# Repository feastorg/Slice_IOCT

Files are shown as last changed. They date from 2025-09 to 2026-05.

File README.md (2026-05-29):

# Slice Template

Rugged digital I/O controller slice with isolated inputs and protected outputs for industrial sensors and actuators.

Template for creating BREAD slices. Features Arduino Nano, small dimensions (70x100mm), 2 layers, and this is the second revision (TEMP_NANO_S2L-r2).

## Introduction

This Slice is designed to be a rugged digital input and output slice that can interface directly with 24V industrial sensors and actuators. It mimics a PLC-style IO module for the BREADS system. It prioritizes input protection, reliable switching, and compatibility with common field devices.

## Usage

[Explain how to use the project. Include examples and screenshots if applicable.]

## Documentation

Please refer to the [docs](/docs) for more info.

---

<div align="center">
  <p>
    
    
  </p>
</div>

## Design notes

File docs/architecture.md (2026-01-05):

---
title: "Architecture Overview"
description: "High-level architecture: electrical, firmware, and mechanical design notes."
---

Overview of the electrical, firmware, and mechanical design of this Slice.

## Rough Plan for SLC_IOCT

TODO: remove this and disperse relevant info into appropriate sections below as they are fleshed out.

**Goal / Description:**

- Create a slice for rugged **digital I/O** control in industrial or field settings.
- Interface directly with **24 V sensors and actuators**.
- Mimics a simple **PLC-style I/O module** for the BREADS system.
- Prioritize **input protection**, reliable switching, and compatibility with common field devices.

**Design Plan:**

- 4–8 opto-isolated digital inputs (24 V-compatible)
- 4–8 protected digital outputs using onboard SSR relays
- TVS protection, flyback diodes for inductive loads

**Applications:**

- Switches, proximity sensors, and relays in automation systems
- Basic on/off control of 24 V field devices
- Rugged I/O for robotics, process control, or lab automation

## 🧠 Purpose

<!-- Briefly describe the function of the Slice -->

This Slice is designed to be a rugged digital input and output slice that can interface directly with 24V industrial sensors and actuators. It mimics a PLC-style IO module for the BREADS system. It prioritizes input protection, reliable switching, and compatibility with common field devices.

## 🔌 Interfaces

| Signal | Connector  | Direction | Voltage | Notes |
| --- | --- | --- | --- | --- |
| IN1 | Screw down | Input | 24V | High voltage input  |
| IN2 | Screw down | Input | 24V | High voltage input  |
| IN3 | Screw down | Input | 24V | High voltage input  |
| IN4 | Screw down | Input | 24V | High voltage input  |
| IN5 | Screw down | Input | 24V | High voltage input  |
| IN6 | Screw down | Input | 24V | High voltage input  |
| OUT1 | Screw down | Output | 12V/24V | High voltage output |
| OUT2 | Screw down | Output | 12V/24V | High voltage output |
| OUT3 | Screw down | Output | 12V/24V | High voltage output |
| OUT4 | Screw down | Output | 12V/24V | High voltage output |

## 🪛 MCU Pin Mapping

| MCU Pin | Function | Net  | Notes |
| --- | --- | ---- | ----- |
| D6 | IN1 | IN1  | |
| D7 | IN3 | IN3  | |
| D8 | IN5 | IN5  | |
| D9 | IN6 | IN6  | |
| D10 | IN4 | IN4  | |
| D11 | IN2 | IN2  | |
| A0 | OUT1 | OUT1 | |
| A1 | OUT2 | OUT2 | |
| A2 | OUT3 | OUT3 | |
| A3 | OUT4 | OUT4 | |

### DUMP

- Supported MCU Dev Boards:
  - Arduino Nano Original (ATMega328P)
  - Arduino Nano Every (ATMega4809)
  - STM32 Nucleo-32 series (e.g. L432KC, F303K8)
  - Other Nano-format boards also supported:
    - Any MCU board using the standard Arduino Nano pinout and 0.1" dual-row 15x2 header format
    - Nano ESP32 and ESP32-S2 variants with Nano footprint (e.g. Nano ESP32 by Arduino, or 3rd party clones)
    - RP2040 Nano-form boards (e.g. Nano RP2040 Connect, Seeed Studio RP2040 Nano)
    - CH32V203 or CH32V003 Nano-format RISC-V dev boards

## 🔋 Power Domains

- Logic power: 5V
- High-current domain: 12V/24V

## 🧩 Mechanical

- Mounting pattern: ...
- Dimensions: ...
- Notes: ...

---

<!-- Optional: Add block diagrams or images under docs/assets/ -->

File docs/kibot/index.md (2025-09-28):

---
title: "KiBot Outputs"
description: "Index for KiBot-generated PCB artifacts."
layout: "page"
---

These are the docs & KiBot Outputs for Slice TEMP NANO S2L r2

The following files were generated from the latest PCB build:

- [Schematic.pdf](./Schematic.pdf)
- [PCB.pdf](./PCB.pdf)
- [kibot.log](./kibot.log)
- [BREAD_Slice-bom.html](./BREAD_Slice-bom.html)
- [BREAD_Slice-ibom.html](./BREAD_Slice-ibom.html)

_Last updated automatically on 2025-09-28 at 17:45:11 UTC by KiBot via GitHub Actions._

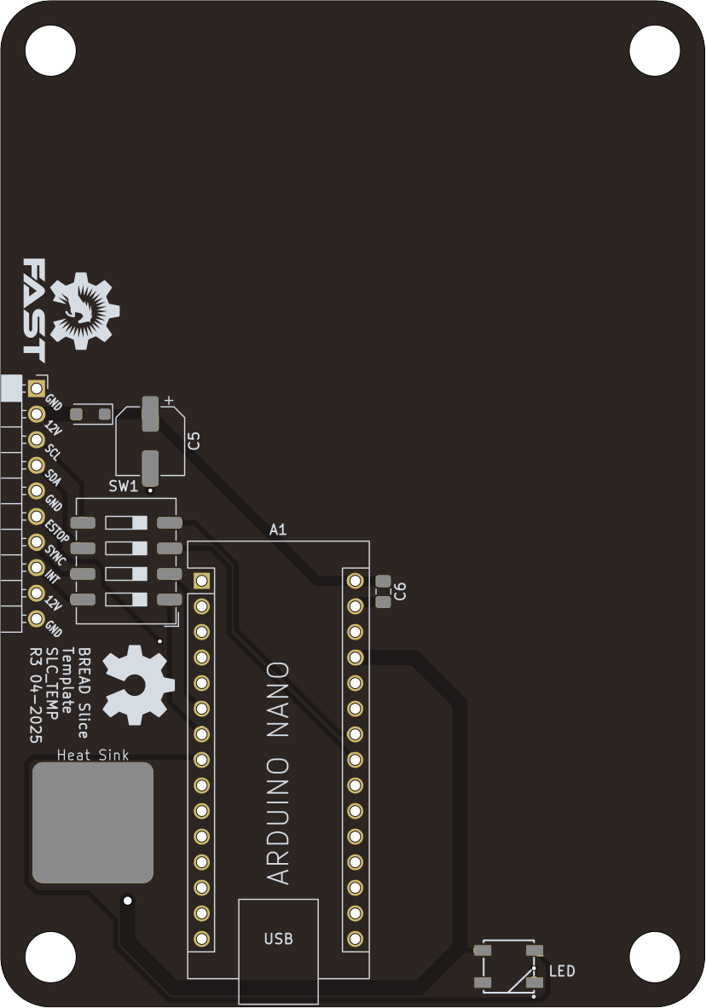
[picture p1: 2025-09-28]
docs/assets/boards/board_top.png

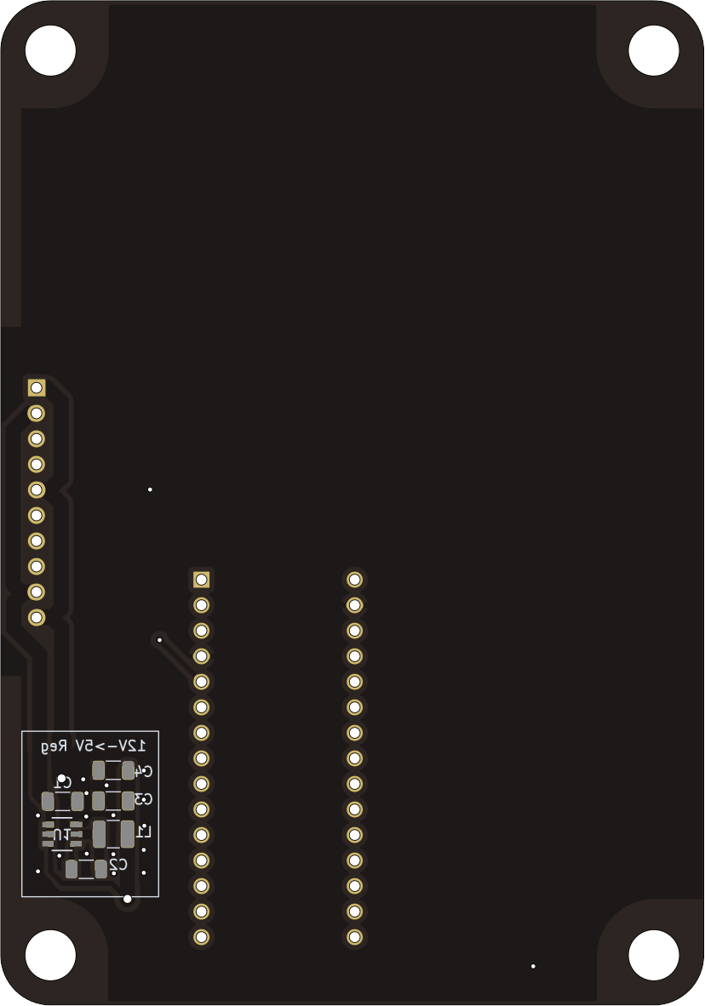
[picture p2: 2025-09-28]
docs/assets/boards/board_bottom.png

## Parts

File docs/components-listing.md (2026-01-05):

# Componments Listing

24v input protection electrolytic cap: https://www.digikey.ca/en/products/detail/panasonic-electronic-components/EEE-FK1V100UR/766003

To use:

- [12 POS - Fixed Terminal Blocks PTSA 0.5/12-2.5-Z 12P 2.5MM 45DEG - Mouser Canada](https://mou.sr/3Xod5Gt)
- [2 POS - Fixed Terminal Blocks PTSA 1.5/2-3.5-Z 2P 3.5MM 45DEG - Mouser Canada](https://mou.sr/3LWcRnp)

Diff number of positions of same line:

- [Fixed Terminal Blocks PTSA 0.5/ 4-2.5-F](https://mou.sr/4qVzBUy)
- [Fixed Terminal Blocks PTSA 0.5/16-2.5-Z](https://mou.sr/3JO0I3o)
- [Fixed Terminal Blocks PTSA 1.5/16-3.5-Z](https://mou.sr/4qV1MDa)

Other options that cam should move somewhere as he gets his shit together deciding a connector series to main (we should have main PTSA since it offers 2.5 and 3.5mm and then maybe LPT for higher power use):

- [LPT(A) 2.5 Lever Push-In Terminal Blocks - Mouser Search](https://www.mouser.ca/c/connectors/terminal-blocks/fixed-terminal-blocks/?marcom=196874227&instock=y)
- [TDPT 2,5/ 2-SP-5,08 - PCB terminal block - Phoenix Contact Site](https://www.phoenixcontact.com/en-ca/products/printed-circuit-board-terminal-tdpt-25-2-sp-508-1017503)
- [LPT 2,5/ 4-5,0 - PCB terminal block - Phoenix Contact Site](https://www.phoenixcontact.com/en-ca/products/printed-circuit-board-terminal-lpt-25-4-50-1190299)
- [SPTA 1/ 2-3,5 - PCB terminal block - Phoenix Contact Site](https://www.phoenixcontact.com/en-ca/products/printed-circuit-board-terminal-spta-1-2-35-1752104)

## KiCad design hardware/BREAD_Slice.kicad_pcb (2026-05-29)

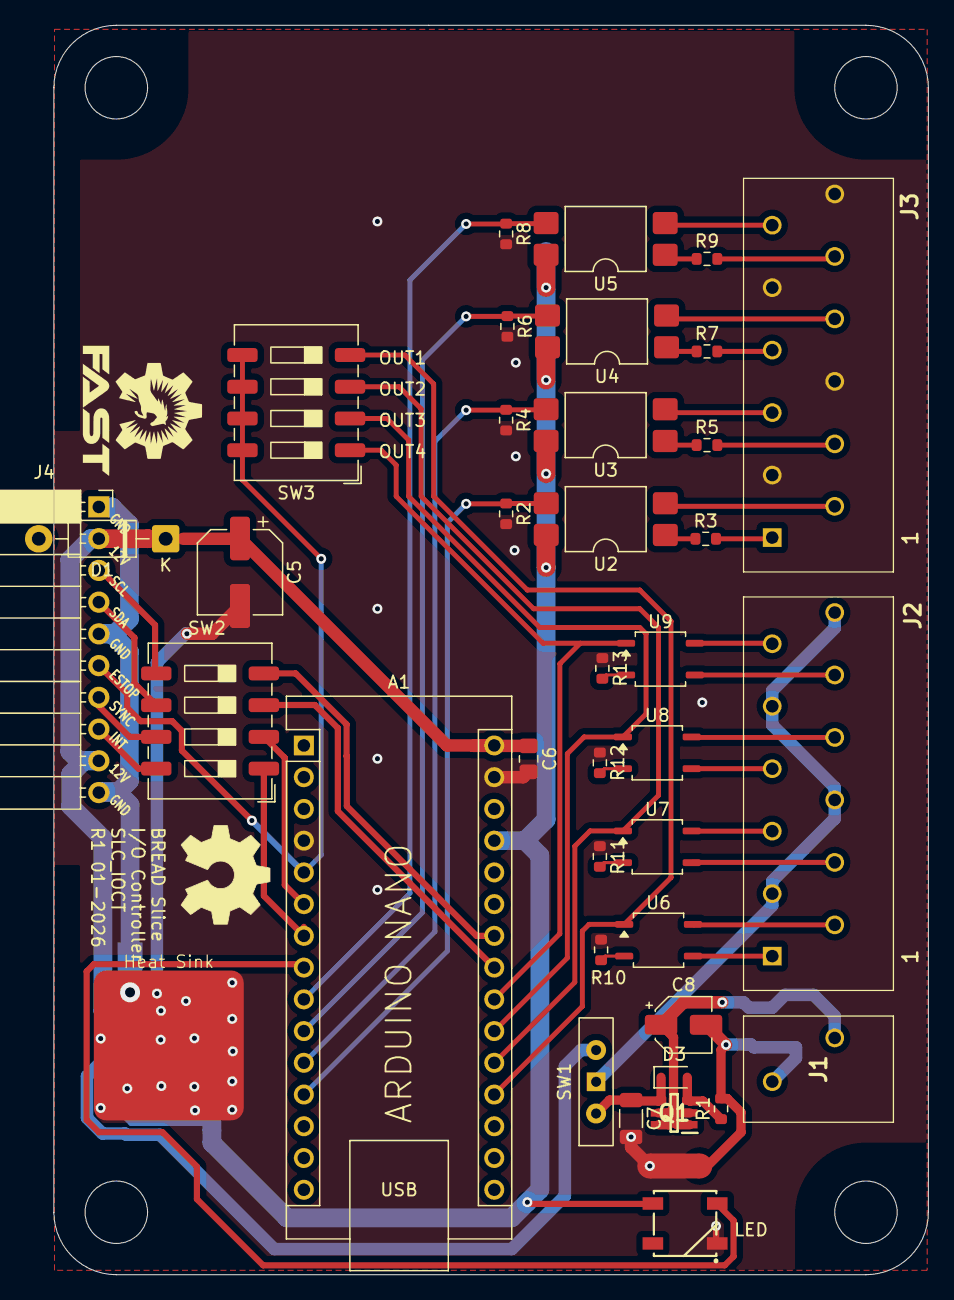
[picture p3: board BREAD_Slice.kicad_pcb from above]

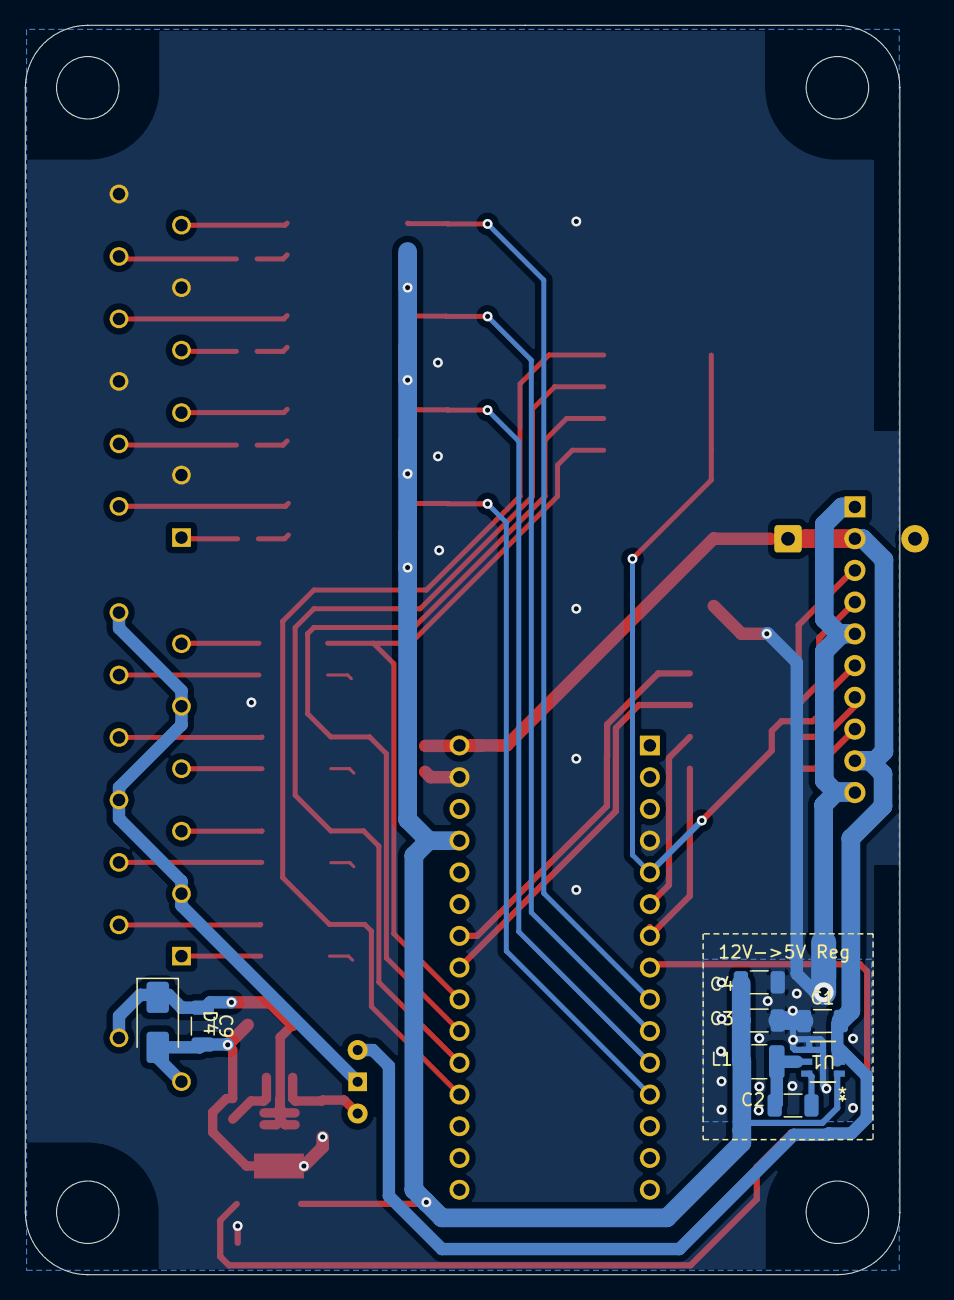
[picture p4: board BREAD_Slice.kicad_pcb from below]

Board: 2 copper layers, 70.0 x 100.0 mm, 53 parts (9 on the bottom side), 54 nets.

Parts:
A1: Arduino_Nano_v3.x; Arduino_Nano
C1: 10u; C_1206_3216Metric
C2: 100nF; C_1206_3216Metric
C3, C4: 22uF; C_1206_3216Metric
C5: 47u 25V; CP_Elec_6.3x7.7
C6: 0.1u; C_0805_2012Metric_Pad1.18x1.45mm_HandSolder
C7, C9: 100n; C_1206_3216Metric
C8: 10u; CP_Elec_4x5.8
D1: 1N4007; D_DO-41_SOD81_P10.16mm_Horizontal
D2: WS2812B_5050; WS2812-5050-4PIN
D3: MM3Z18VT1G; D_SOD-323
D4: SMAJ24CA; D_SMA
H1, H2, H3, H4: MountingHole; MountingHole_5mm
HS1: Heatsink_Pad; Thermal Pad
J1: 1985195
J2, J3: 1990106
J4: Conn_01x10_Socket; PinSocket_1x10_P2.54mm_Horizontal
L1: 4.7uH; L_1210_3225Metric
NT1, NT2: NetTie_2; NetTie-2_SMD_Pad2.0mm
Q1: NTGS4111PT1G; SOT95P275X110-6N
R1: 100k; R_0603_1608Metric
R2, R3, R4, R5, R6, R7, R8, R9: 1k; R_0603_1608Metric
R10, R11, R12, R13: 1.3k; R_0603_1608Metric
Ref**: Val**; OSHW_Logo_8mm
SW1: SW_SPDT; SW_Slide-03_Wuerth-WS-SLTV_10x2.5x6.4_P2.54mm
SW2, SW3: SW_DIP_x04; SW_DIP_SPSTx04_Slide_9.78x12.34mm_W8.61mm_P2.54mm
U1: AP63205; SOIC_05WU-7_DIO
U2, U3, U4, U5: LTV-817S; SMDIP-4_W9.53mm
U6, U7, U8, U9: CPC1002N; SOP-4_3.8x4.1mm_P2.54mm

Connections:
+5V: A1.27 (+5V), C3.2, C4.2, D2.1 (VDD), L1.2, U1.1 (FB), U2.4, U3.4, U4.4, U5.4
+12V: C1.2, D1.2 (A), J4.2, J4.9, SW1.1 (A), U1.2 (EN), U1.3 (VIN)
/+24V: C7.1, D3.1 (K), Q1.4 (S), SW1.3 (C)
/ESTOP: A1.5 (D2), J4.6, SW3.5, SW3.6, SW3.7, SW3.8
/I2C_CLK: A1.24 (A5), SW2.4
/I2C_DAT: A1.23 (A4), SW2.3
/IN1: A1.12 (D9), R2.1, U2.3
/IN1+: J3.1, R3.2
/IN1-: J3.2, U2.2
/IN2: A1.11 (D8), R4.1, U3.3
/IN2+: J3.4, R5.2
/IN2-: J3.5, U3.2
/IN3: A1.10 (D7), R6.1, U4.3
/IN3+: J3.7, R7.2
/IN3-: J3.8, U4.2
/IN4: A1.9 (D6), R8.1, U5.3
/IN4+: J3.10, R9.2
/IN4-: J3.11, U5.2
/Input Power Protection/INPUT_GND: C8.2, C9.2, D4.2 (A2), J1.2, NT2.2, R1.2
/Input Power Protection/INPUT_VDD: C8.1, C9.1, D4.1 (A1), J1.1, Q1.1 (D_1), Q1.2 (D_2), Q1.5 (D_3), Q1.6 (D_4)
/OUT1: A1.19 (A0), SW3.4, U6.1
/OUT1+: J2.2, U6.4
/OUT1-: J2.1, U6.3
/OUT2: A1.20 (A1), SW3.3, U7.1
/OUT2+: J2.4, U7.3
/OUT2-: J2.5, U7.4
/OUT3: A1.21 (A2), SW3.2, U8.1
/OUT3+: J2.7, U8.3
/OUT3-: J2.8, U8.4
/OUT4: A1.22 (A3), SW3.1, U9.1
/OUT4+: J2.10, U9.3
/OUT4-: J2.11, U9.4
/VFIELD: J2.3, J2.6, J2.9, J2.12, SW1.2 (B)
/slice_template/I2C_CLK: J4.3, SW2.5
/slice_template/I2C_DAT: J4.4, SW2.6
/slice_template/INT: J4.8, SW2.8
/slice_template/INT/CAN_{CS}: A1.7 (D4), SW2.1
/slice_template/LED: A1.8 (D5), D2.4 (DIN)
/slice_template/SYNC: J4.7, SW2.7
/slice_template/SYNC/CAN_{INT}: A1.6 (D3), SW2.2
/slice_template/VIN: A1.30 (VIN), C5.1, C6.1, D1.1 (K)
GND: A1.4 (GND), A1.29 (GND), C1.1, C3.1, C4.1, C5.2, C6.2, C7.2, D2.3 (VSS), HS1.1, J3.3, J3.6, J3.9, J3.12, NT1.1, NT2.1, R2.2, R4.2, R6.2, R8.2, R10.1, R11.1, R12.1, R13.1, U1.4 (GND)
GNDPWR: J4.1, J4.5, J4.10, NT1.2
unnamed: D3.2 (A), Q1.3 (G), R1.1
unnamed: R3.1, U2.1
unnamed: R5.1, U3.1
unnamed: R7.1, U4.1
unnamed: R9.1, U5.1
unnamed: R10.2, U6.2
unnamed: R11.2, U7.2
unnamed: R12.2, U8.2
unnamed: R13.2, U9.2
unnamed: C2.2, U1.6 (BST)
unnamed: C2.1, L1.1, U1.5 (SW)

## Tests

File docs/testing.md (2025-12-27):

---
title: "Testing Instructions"
description: "Hardware and firmware testing checklist and procedures."
---

Testing procedures for this Slice. Covers manual validation and optional automated checks.

## ✅ Hardware Checklist

- [ ] Visual inspection (solder joints, polarity, orientation)
- [ ] No shorts across power rails
- [ ] All headers and connectors populated

## ⚡ Power-On Verification

1. Apply logic power (e.g., 5V).
2. Confirm LED heartbeat (if present).
3. Measure voltage rails at test points.

## 📟 Functional Tests

| Test | Method | Expected Result |
| --- | --- | --- |
| UART output | Connect USB-Serial, open terminal | Data output at expected baud rate |
| Input test  | Drive digital input | MCU registers or reacts accordingly |
| Output test | Scope or multimeter at output | Output toggles or changes as coded  |

## 🔁 Firmware Regression (if present)

```bash
pio run -t test
```

## 📷 Test Setup

<!-- insert annotated image of bench setup under docs/assets/ and insert here -->

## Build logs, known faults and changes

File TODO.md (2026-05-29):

# TODO

## Pass 1 — CI Pipeline

- [x] Pipeline added
- [x] DRC: FAIL — 20 errors (shorting_items, courtyards_overlap, solder_mask_bridge, unconnected_items)
- [x] ERC: FAIL — 17 warnings (missing custom KMLib libraries, symbol mismatches)
- [ ] Fab: SKIPPED (blocked by ERC pre-flight)
- [ ] gen-kibot-index: SKIPPED
- [ ] deploy-pages: SKIPPED

### DRC Errors (20)

- shorting_items: nets /VFIELD, +12V, /slice_template/VIN, /+24V shorting (6 errors)
- courtyards_overlap (1 error)
- solder_mask_bridge: front/rear aperture bridges between different nets (6 errors)
- unconnected_items: missing connections (7 errors)

### ERC Warnings (17)

- Missing custom libraries: KMLib_Connectors, KMLib_Mounting, KMLib_IC_SMD, KMLib_IC_Power, KMLib_IC_Digital, KMLib_Boards_Modules, KMLib_IC_MCU_MPU, KMLib_Discrete_Semiconductors
- Symbol mismatches: CPC1002N (Relay_SolidState), LTV-817S (Isolator)

## Pass 2 — Pre-Fab Review

- [ ] Fix 6x shorting items (VFIELD, +12V, VIN, +24V nets)
- [ ] Fix 1x courtyard overlap
- [ ] Fix 6x solder mask bridge errors
- [ ] Fix 7x unconnected items
- [ ] Add missing KMLib custom libraries or remap symbols
- [ ] Verify BOM completeness and sourcing
- [ ] Confirm board outline and mounting holes
- [ ] Footprint verification against datasheets
- [ ] Design review sign-off

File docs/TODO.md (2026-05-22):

# TODO

- [ ] Update connectors
- [x] Add dip switches to allow for inputs to connect to e-stop
- [ ] Connect inputs to interrupt pins — maybe change MCU to allow for more interrupts

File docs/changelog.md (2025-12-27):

---
title: "Changelog"
description: "Project changelog following Keep a Changelog conventions."
---

Follows [Keep a Changelog](https://keepachangelog.com/en/1.0.0/). Use semantic versioning.

## [Unreleased]

- Write here...

## [v0.0.0] – 2025-XX-YY

### Added

- Initial board schematic and layout

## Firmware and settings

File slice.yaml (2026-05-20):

schema_version: "1.0"

# ── Identity ──────────────────────────────────────────────────────────────────
id: "slice-ioct"
name: "Industrial Digital I/O Controller"
status: "prototype"
category: "interface"

summary: "PLC-style 6-input 4-output isolated digital I/O slice for 24V field devices."
description: null

# ── Versioning ────────────────────────────────────────────────────────────────
version:
  hardware: "0.1.0"
  firmware: null
  manifest: "0.1.0"

# ── Compatibility ─────────────────────────────────────────────────────────────
compatibility:
  slice_spec: ">=0.1.0 <0.2.0"
  crumbs_protocol: null
  anolis_provider_api: null

# ── Hardware ──────────────────────────────────────────────────────────────────
hardware:
  mcu:
    type: "dev-board-socket"
    form_factor: "nano"
    primary: "ATmega328P"
    supported:
      - "ATmega328P"
      - "ATmega4809"
  primary_ic:
    manufacturer: "IXYS/Littelfuse"
    part_number: "CPC1002N"
  hw_gen_current: 1
  hw_gen_supported: [1]
  pcb:
    layers: 2
    thickness: "1.6mm"
    copper_weight: "1oz"
    dimensions: "70mm x 100mm"
  connectors:
    - ref: "J1"
      type: "slice-bus-10pin"
      purpose: "power-and-i2c"
    - ref: "J_IN"
      type: "terminal-block-12pos"
      purpose: "24v-digital-inputs"
    - ref: "J_OUT"
      type: "terminal-block-8pos"
      purpose: "ssr-digital-outputs"
  mounting:
    pattern: "slice-standard-v0"
    hole_size: "M3"
    inset: "5mm"
  pcb_color_prototype: null
  pcb_color_production: null
  enclosure:
    supported: false
    path: null

# ── Electrical ────────────────────────────────────────────────────────────────
electrical:
  input_voltage: "12V"
  logic_voltage: "5V"
  max_current: null
  protection:
    reverse_polarity: true
    input_esd: true
    fuse: false
  isolation:
    present: true

# ── Interfaces ────────────────────────────────────────────────────────────────
interfaces:
  host:
    type: "i2c"
    address_default: null
    address_configurable: false
  data:
    inputs:
      - name: "IN1"
        type: "digital-24v"
      - name: "IN2"
        type: "digital-24v"
      - name: "IN3"
        type: "digital-24v"
      - name: "IN4"
        type: "digital-24v"
      - name: "IN5"
        type: "digital-24v"
      - name: "IN6"
        type: "digital-24v"
    outputs:
      - name: "OUT1"
        type: "ssr-24v"
      - name: "OUT2"
        type: "ssr-24v"
      - name: "OUT3"
        type: "ssr-24v"
      - name: "OUT4"
        type: "ssr-24v"

# ── Capabilities ──────────────────────────────────────────────────────────────
capabilities:
  - id: "digital_input"
    channels: 6
    control_modes: []
  - id: "ssr_output"
    channels: 4
    control_modes: ["on_off"]

# ── Firmware ──────────────────────────────────────────────────────────────────
firmware: null

# ── Protocol ──────────────────────────────────────────────────────────────────
protocol: null

# ── Software ──────────────────────────────────────────────────────────────────
software: null

# ── Artifacts ─────────────────────────────────────────────────────────────────
artifacts:
  schematic: "hardware/BREAD_Slice.kicad_sch"
  pcb: "hardware/BREAD_Slice.kicad_pcb"
  firmware: null
  docs: "docs/"
  bom: null
  gerbers: null
  pick_and_place: null
  datasheets: []

# ── Manufacturing ─────────────────────────────────────────────────────────────
manufacturing:
  assembly_type: "manual"
  preferred_fab: null
  dnp_parts: []
  critical_parts: []
  substitutions_allowed: true

# ── Validation ────────────────────────────────────────────────────────────────
validation:
  status: "not_validated"
  tested_revisions: []
  tests:
    electrical: false
    firmware: false
    environmental: false
    integration: false
  known_issues: []

# ── Safety ────────────────────────────────────────────────────────────────────
safety:
  hazards:
    - "24V field wiring"
  max_safe_voltage: "24V DC"
  intended_environment: "lab"
  not_for:
    - "human safety critical systems"

# ── Dependencies ──────────────────────────────────────────────────────────────
dependencies:
  hardware: []
  firmware_libraries: []
  software_packages: []

# ── Relations ─────────────────────────────────────────────────────────────────
related:
  supersedes: null
  superseded_by: null
  variants: []
  compatible_slices: []

# ── Maintainers ───────────────────────────────────────────────────────────────
maintainers:
  - name: "Cameron Brooks"
    role: "owner"

# ── License ───────────────────────────────────────────────────────────────────
license:
  hardware: "CERN-OHL-S-2.0"
  firmware: null
  software: null
  docs: "CC-BY-4.0"

# ── Repository ────────────────────────────────────────────────────────────────
repository:
  url: "https://github.com/feastorg/Slice_IOCT"
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

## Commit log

2025-09-28 📄 KiBot index + board renders (auto)
2025-11-11 Finished draft 1, still need documentation and review
    [BREAD_Slice.kicad_pcb, BREAD_Slice.kicad_sch]
2025-11-11 some revisions and schem and brd
    [BREAD_Slice.kicad_pcb, BREAD_Slice.kicad_sch, input_pwr_rev_prot.kicad_sch]
2025-11-11 further revision of schem, add subsheets
    [BREAD_Slice.kicad_sch, isolated_input.kicad_sch, ssr_out_cpc1002n.kicad_sch]
2025-11-11 update schem
    [BREAD_Slice.kicad_pcb, BREAD_Slice.kicad_sch]
2025-11-12 finalize revision of schematic
    [BREAD_Slice.kicad_pcb, BREAD_Slice.kicad_sch, input_pwr_rev_prot.kicad_sch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]
2025-12-27 Added new conenctor
    [BREAD_Slice.kicad_pcb, BREAD_Slice.kicad_sch]
2025-12-27 updated routing and silkscreen
    [BREAD_Slice.kicad_pcb]
2026-01-02 go over changes with ian, fix courtyard outline
    [BREAD_Slice.kicad_pcb]
2026-01-03 fix some footprint links
    [input_pwr_rev_prot.kicad_sch]
2026-01-04 revision of symbol attachment and clear out old layout and start new; kml-custom to kmlib-local
    [BREAD_Slice.kicad_pcb, BREAD_Slice.kicad_sch, input_pwr_rev_prot.kicad_sch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]
2026-01-05 rerouted using PTSA connectors
    [BREAD_Slice.kicad_pcb, BREAD_Slice.kicad_sch, ssr_out_cpc1002n.kicad_sch]
2026-01-11 rerouted again with new kml library
    [BREAD_Slice.kicad_pcb]
2026-02-09 update all to KMLib, untrack backups in gitignore, and revise routing on board to simplify
    [BREAD_Slice.kicad_pcb, BREAD_Slice.kicad_sch, isolated_input.kicad_sch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]
2026-05-22 added dip switches to IOCT
    [BREAD_Slice.kicad_pcb, BREAD_Slice.kicad_sch, slice_template.kicad_sch]
2026-05-29 added silkscreen for dip switches
    [BREAD_Slice.kicad_pcb]
